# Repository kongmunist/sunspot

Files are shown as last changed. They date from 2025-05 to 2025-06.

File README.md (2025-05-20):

# Sunspot: Solar-Powered LoRa Camera System

Sunspot is a sticker-based camera system that uses LoRa technology to transmit images to the web, powered entirely by solar energy. The system operates without the need for battery charging, making it a truly autonomous monitoring solution.

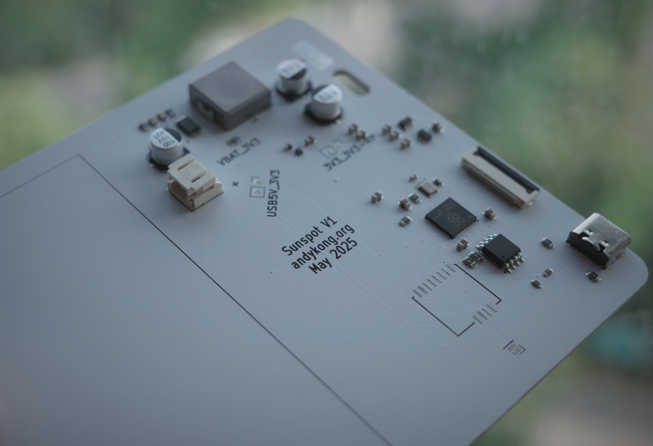
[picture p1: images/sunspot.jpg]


## Key Features

- **Zero Maintenance**: Charges itself entirely on harvested solar energy
- **LoRa Connectivity**: Long-range, low-power wireless communication
- **Sticker Form Factor**: Ultra-thin, flexible design for easy deployment
- **Web Integration**: Images automatically uploaded to web dashboard

## Applications

- Environmental monitoring
- Wildlife tracking
- Remote surveillance
- Agricultural monitoring
- Infrastructure inspection

## Project Structure

```
sunspot/
├── firmware/
│   ├── CameraWebServer/    # Camera web server implementation
│   └── jpeg_stream_viewer.py  # JPEG stream viewer utility
└── sunspotv1/             # KiCad PCB design files
    ├── sunspotv1.kicad_sch    # Schematic file
    ├── sunspotv1.kicad_pcb    # PCB layout file
    └── sunspotv1.kicad_pro    # Project file
```

## Hardware

The hardware design is implemented in KiCad and includes:
- Custom PCB design (sunspotv1)
- Schematic and PCB layout files
- Project configuration

## Firmware

The firmware component includes:
- Camera web server implementation
- JPEG stream viewer utility for camera feed visualization

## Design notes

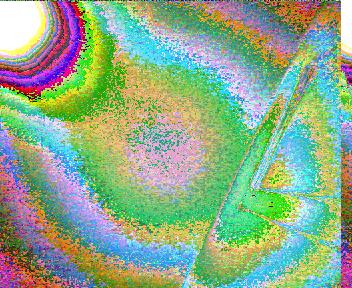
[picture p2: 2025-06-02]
firmware/rp2040_ov2640/penis copy.jpg

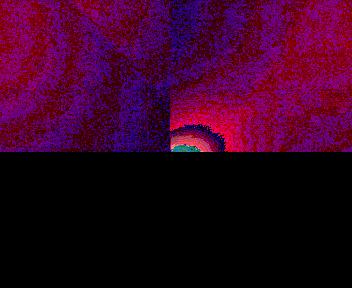
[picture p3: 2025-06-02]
firmware/rp2040_ov2640/yaga.jpg

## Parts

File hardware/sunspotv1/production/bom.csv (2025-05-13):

Designator | Footprint | Quantity | Value | LCSC Part #
AE1 | PinHeader_1x01_P2.54mm_Vertical | 1 | Antenna
C1, C7 | 0603 | 2 | 12pF
C10, C4, C6, C8, C9 | 0805 | 5 | 10uF
C11, C5 | 0805 | 2 | 4.7uF
C15, C17, C18, C19 | 0805 | 4 | 1uF
C21, C25 | 0805 | 2 | 1nF
C23, C26, C27 | C_Elec_6.3x5.4 | 3 | RVT1C101M0605
IC1 | Wio_SM1262_LoRa | 1 | LoRa SX1262
J1 | JST_PH_S2B-PH-SM4-TB_1x02-1MP_P2.00mm_Horizontal | 1 | HCZZ0451-2
J10 | Hirose_FH12-24S-0.5SH_1x24-1MP_P0.50mm_Horizontal | 1 | 05A20L24P
J2 | SolderJumper-2_P1.3mm_Open_RoundedPad1.0x1.5mm | 1 | Conn_01x02_Socket
J4, J7 | PinHeader_1x02_P2.54mm_Vertical | 2 | Conn_01x02_Socket
J5 | USB_C_Receptacle_GCT_USB4105-xx-A_16P_TopMnt_Horizontal | 1 | USB-TYPE-C-018
J9 | C60_quarter_thruboardholes | 1 | Conn_01x02_Socket
L6 | L_TaiTech_TMPC1265_13.5x12.5mm | 1 | MDA1350-220M
L7 | 0603 | 1 | CPY160808T-2R2M-NP
R1, R5 | 0805 | 2 | 1kΩ
R14 | 0603 | 1 | 120kΩ
R15 | 0805 | 1 | 51kΩ
R2 | 0805 | 1 | 10kΩ
R3, R4 | 0603 | 2 | 33Ω
R6, R7 | 0805 | 2 | 1MΩ
R8, R9 | 0805 | 2 | 5.1kΩ
U1 | SOT-23-5 | 1 | CL9293A12L5M
U2 | QFN-56-1EP_7x7mm_P0.4mm_EP3.2x3.2mm | 1 | RP2040
U3 | SOIC_1040T_STM-L | 1 | SPV1040T
U4 | SOIC-8_5.3x5.3mm_P1.27mm | 1 | W25Q16JVSSIQ
U5 | SOT-23-5 | 1 | XC6219B282MR
U6 | DRY0006A | 1 | TPS62237
Y1 | Crystal_SMD_3225-4Pin_3.2x2.5mm | 1 | X322512MSB4SI

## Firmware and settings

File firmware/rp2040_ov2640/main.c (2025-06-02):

#include <stdio.h>
#include "pico/stdlib.h"
#include "ov2640.h"

// const int PIN_LED = 25;

// const int PIN_CAM_SIOC = 5; // I2C0 SCL
// const int PIN_CAM_SIOD = 4; // I2C0 SDA
// const int PIN_CAM_RESETB = 2;
// const int PIN_CAM_XCLK = 3;
// const int PIN_CAM_VSYNC = 16;
// const int PIN_CAM_Y2_PIO_BASE = 6;

const int PIN_CAM_SIOC = 15;   // I2C0 SCL
const int PIN_CAM_SIOD = 14;   // I2C0 SDA
const int PIN_CAM_RESETB = 13 ;
const int PIN_CAM_XCLK = 8;
const int PIN_CAM_VSYNC = 12;
const int PIN_CAM_Y2_PIO_BASE = 0;  // DATA2 is GPIO0, and DATA0–DATA7 are non-contiguous but we'll map in software


const uint8_t CMD_REG_WRITE = 0xAA;
const uint8_t CMD_REG_READ = 0xBB;
const uint8_t CMD_CAPTURE = 0xCC;

uint8_t image_buf[352*288*2];
int main() {
	stdio_init_all();

    for (int i = 0; i < 2; ++i) {
        printf("Hello, world!%d\n", i);
        sleep_ms(1000);
    }
    printf("Booted!\n");

	gpio_init(26);
	gpio_set_dir(26, GPIO_OUT);
	gpio_put(26, 1);  // set GPIO26 HIGH
	
	sleep_ms(10);

    struct ov2640_config config;
    config.sccb = i2c1;
    config.pin_sioc = PIN_CAM_SIOC;
    config.pin_siod = PIN_CAM_SIOD;

    config.pin_resetb = PIN_CAM_RESETB;
    config.pin_xclk = PIN_CAM_XCLK;
    config.pin_vsync = PIN_CAM_VSYNC;
    config.pin_y2_pio_base = PIN_CAM_Y2_PIO_BASE;

    config.pio = pio0;
    config.pio_sm = 0;

    config.dma_channel = 0;
    config.image_buf = image_buf;
    config.image_buf_size = sizeof(image_buf);

    ov2640_init(&config);
	printf("post OV init !\n");

    ov2640_reg_write(&config, 0xff, 0x01);
    uint8_t midh = ov2640_reg_read(&config, 0x1C);
    uint8_t midl = ov2640_reg_read(&config, 0x1D);
    printf("MIDH = 0x%02x, MIDL = 0x%02x\n", midh, midl);


    // Reading register
    // sleep_ms(1000);
    // printf("reading register...\n");
    // int reg = 0x1C;
    // uint8_t value = ov2640_reg_read(&config, (uint8_t)reg);
    // printf("reg = 0x%02x, value = 0x%02x\n", reg, value);


    // // Reading camera frame
    sleep_ms(100);

    // printf("capturing frame OV2640\n");
    // ov2640_capture_frame(&config);
    // // // config.image_buf_size
    // printf("frame got! size = %d\n", config.image_buf_size);

    // for (size_t i = 0; i < config.image_buf_size; ++i) {
    //     putchar(config.image_buf[i]);
    // }



    while (true) {
        int cmd = getchar();  // wait for 1 byte from USB serial

        if (cmd == EOF) continue;

        // gpio_put(PIN_LED, !gpio_get(PIN_LED));

        if (cmd == CMD_REG_WRITE) {
            int reg = getchar();
            int value = getchar();
            if (reg == EOF || value == EOF) continue;

            ov2640_reg_write(&config, (uint8_t)reg, (uint8_t)value);

        } else if (cmd == CMD_REG_READ) {
            int reg = getchar();
            if (reg == EOF) continue;

            uint8_t value = ov2640_reg_read(&config, (uint8_t)reg);
            putchar(value);

        } else if (cmd == CMD_CAPTURE) {
            ov2640_capture_frame(&config);

            for (size_t i = 0; i < config.image_buf_size; ++i) {
                putchar(config.image_buf[i]);
                // printf("%02x", config.image_buf[i]);
            }

            // clear serial input output buffer
        }
    }

    return 0;
}

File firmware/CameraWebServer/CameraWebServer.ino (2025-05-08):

/**********************************************************************
 *  XIAO-ESP32S3  ──>  SSDV-over-Serial demo
 *
 *  – Captures a QVGA JPEG frame
 *  – Encodes it into 256-byte SSDV packets with RS(255,223) FEC
 *  – Streams the packets out of the USB-CDC port at 921 600 bps
 *
 *  Packet format is byte-for-byte identical to the HAB SSDV spec,
 *  so any existing ground-station decoder will work unchanged.
 *
 *  Olivia Li – 2025-05-06
 *********************************************************************/
#include "esp_camera.h"
#include "ssdv.h"          // fsphil SSDV encoder (C)
#include "camera_pins.h"

// --------------------------- USER CONFIG ---------------------------
#define CAMERA_MODEL_XIAO_ESP32S3
static const char  CALLSIGN[7] = "KC1UQM";   // 6 chars + '\0'
static uint8_t     image_id    = 0;         // rolls over at 255
const uint32_t     DATA_BAUD   = 921600;    // USB-CDC can handle this
// -------------------------------------------------------------------

static uint8_t pkt[SSDV_PKT_SIZE];          // 256-byte packet buffer
static ssdv_t  ssdv;                        // encoder state

void setup() {
  // 1) High-speed serial for the packets
  Serial.begin(DATA_BAUD);
  Serial.setDebugOutput(false);

  // 2) Camera config (identical to your last working sketch)
  camera_config_t cfg = {
    .ledc_channel   = LEDC_CHANNEL_0,
    .ledc_timer     = LEDC_TIMER_0,
    .pin_d0         = Y2_GPIO_NUM,  .pin_d1 = Y3_GPIO_NUM,
    .pin_d2         = Y4_GPIO_NUM,  .pin_d3 = Y5_GPIO_NUM,
    .pin_d4         = Y6_GPIO_NUM,  .pin_d5 = Y7_GPIO_NUM,
    .pin_d6         = Y8_GPIO_NUM,  .pin_d7 = Y9_GPIO_NUM,
    .pin_xclk       = XCLK_GPIO_NUM,
    .pin_pclk       = PCLK_GPIO_NUM,
    .pin_vsync      = VSYNC_GPIO_NUM,
    .pin_href       = HREF_GPIO_NUM,
    .pin_sccb_sda   = SIOD_GPIO_NUM,
    .pin_sccb_scl   = SIOC_GPIO_NUM,
    .pin_pwdn       = PWDN_GPIO_NUM,
    .pin_reset      = RESET_GPIO_NUM,
    .xclk_freq_hz   = 20'000'000,
    .frame_size     = FRAMESIZE_QVGA,          // 320×240
    .pixel_format   = PIXFORMAT_JPEG,
    .fb_location    = CAMERA_FB_IN_PSRAM,
    .grab_mode      = CAMERA_GRAB_LATEST,
    .jpeg_quality   = 12, .fb_count = 2
  };
  if (!psramFound()) {                       // degrade gracefully
    cfg.frame_size = FRAMESIZE_SVGA;
    cfg.fb_location = CAMERA_FB_IN_DRAM;
    cfg.fb_count = 1;
  }
  if (esp_camera_init(&cfg) != ESP_OK) {
    Serial.println("Camera init failed");    // binary stream not started yet
    while (true) delay(1000);
  }
  sensor_t *s = esp_camera_sensor_get();
  if (s->id.PID == OV3660_PID) {             // aesthetic tweaks
    s->set_vflip(s, 1);
    s->set_brightness(s, 1);
    s->set_saturation(s, -2);
  }
}

void encode_and_send(camera_fb_t *fb) {
  /* 1.  Initialise encoder for this image */
  ssdv_enc_init(&ssdv, (uint8_t*)CALLSIGN, image_id, SSDV_TYPE_STANDARD);
  ssdv_enc_set_buffer(&ssdv, pkt);

  size_t fed = 0;
  const uint8_t *jpeg = fb->buf;
  size_t len  = fb->len;

  /* 2.  Produce packets until EOI */
  while (true) {
    int st = ssdv_enc_get_packet(&ssdv);
    if (st == SSDV_OK) {                     // a full 256-byte pkt ready
      Serial.write(pkt, SSDV_PKT_SIZE);
    }
    else if (st == SSDV_FEED_ME) {           // encoder wants more jpeg data
      size_t chunk = (len - fed) > 128 ? 128 : (len - fed);
      if (chunk == 0) break;                 // shouldn't happen
      ssdv_enc_feed(&ssdv, jpeg + fed, chunk);
      fed += chunk;
    }
    else if (st == SSDV_EOI) {               // done!
      break;
    }
    else {                                   // SSDV_ERROR
      Serial.printf("SSDV err %d\n", st);
      break;
    }
  }
  image_id++;                                // increment for next frame
}

void loop() {
  camera_fb_t *fb = esp_camera_fb_get();
  if (!fb) return;

  encode_and_send(fb);                       // SSDV encoding + TX
  esp_camera_fb_return(fb);                  // free the framebuffer

  /* A QVGA frame ~15 kB → ~90 SSDV pkts (≈23 kB).  At 921 600 bps
     that’s ~200 ms of airtime; 1 s pause keeps  ~4 fps.  */
  delay(1000);
}

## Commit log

2025-05-07 sunspot init
    [sunspotv1.kicad_pcb, sunspotv1.kicad_sch]
2025-05-07 Add firmwareg
    [partitions.csv]
2025-05-08 added footprints for most things
    [sunspotv1.kicad_sch]
2025-05-08 ok footprints done, starting layout
    [sunspotv1.kicad_pcb, sunspotv1.kicad_sch]
2025-05-10 feat: halfway done routing. sunspot v1 prob gonna be too big, a little messy
    [sunspotv1.kicad_pcb, sunspotv1.kicad_sch]
2025-05-10 feat: all routed except camera
    [sunspotv1.kicad_pcb, sunspotv1.kicad_sch]
2025-05-10 removed some random jumperes
    [sunspotv1.kicad_pcb, sunspotv1.kicad_sch]
2025-05-11 finished routing
    [sunspotv1.kicad_pcb, sunspotv1.kicad_sch]
2025-05-11 ok now done, picked right USBc
    [sunspotv1.kicad_pcb, sunspotv1.kicad_sch]
2025-05-13 boards modified to be easier to order assembled.
    [bom.csv, designators.csv, positions.csv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]
2025-05-18 added LED
    [sunspotv1.kicad_pcb, sunspotv1.kicad_sch]
2025-05-20 add power LEDs to the schematic, and hero image
    [sunspotv1.kicad_sch]
2025-05-20 added rp2040 code to begin modding it for sunspot v1
    [sunspotv1.kicad_pcb, sunspotv1.kicad_sch]
2025-05-20 ok, found my error, sda scl switched
2025-05-22 added buttons and RP LED, removed 2nd jumper
    [sunspotv1.kicad_pcb, sunspotv1.kicad_sch]
2025-05-22 added buttons, etc for v2. fixed routing also.
    [sunspotv1.kicad_pcb, sunspotv1.kicad_sch]
2025-05-22 added buttons + labels
    [sunspotv1.kicad_pcb, sunspotv1.kicad_sch]
2025-05-22 added voluntary LED
    [sunspotv1.kicad_pcb, sunspotv1.kicad_sch]
2025-05-22 moved everything to the left to give the camera space
    [sunspotv1.kicad_pcb]
2025-05-30 added debug led i think
    [sunspotv1.kicad_pcb]
2025-06-01 moved v1 board to hardware folder and renamed v2, new copy of v1 boards from github for reference
    [bom.csv, designators.csv, positions.csv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]
2025-06-01 got camera init working, starting to edit shell.py
    [sunspotv1.kicad_pcb, sunspotv1.kicad_sch]
2025-06-02 hanging on vsync, means camera isn't just freerunning
2025-06-02 working, partial images only tho
    [sunspotv2.kicad_sch]
2025-06-05 fix gnd connection for spv1040 on v2
    [sunspotv1.kicad_pcb, sunspotv2.kicad_pcb, sunspotv2.kicad_sch]
2025-06-23 v2 updates to be smaller
    [sunspotv2.kicad_pcb, sunspotv2.kicad_sch]
2025-06-23 v2 done
    [sunspotv2.kicad_pcb]
